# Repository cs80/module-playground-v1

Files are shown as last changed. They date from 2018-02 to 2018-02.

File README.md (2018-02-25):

# module-playground-v1
  Old Crow's Module Playground 10HP Eurorack module using the Adafruit Feather M0/M4 and CircuitPython.
Make sure the feather to be used has at least circuitpython 2.2.x installed as well as the adafruit
circuitpython libraries. See https://github.com/adafruit/circuitpython/releases and
https://learn.adafruit.com/welcome-to-circuitpython/circuitpython-libraries for more info.

  For oc_midicv.py use mpy-cross and place resulting oc_midicv.mpy file in the lib folder of CIRCUITPY:
Rename init_midicv.py to code.py and place in top level of CIRCUITPY: Pre-compiled .mpy is included
here for the lazy hacker. ;)

  The example program oc_midicv.py is too large to run in the M0 memory space which is why it requires
compiling to bytecode (.mpy) to squeeze it down to fit.  mpy-cross is available at the circuitpython
link above.  Note that mpy-cross is a command-line utility.

  The .brd and .sch files are for Eagle CAD for those interested.
  
25-FEB-2018 Scott Rider / The Old Crow

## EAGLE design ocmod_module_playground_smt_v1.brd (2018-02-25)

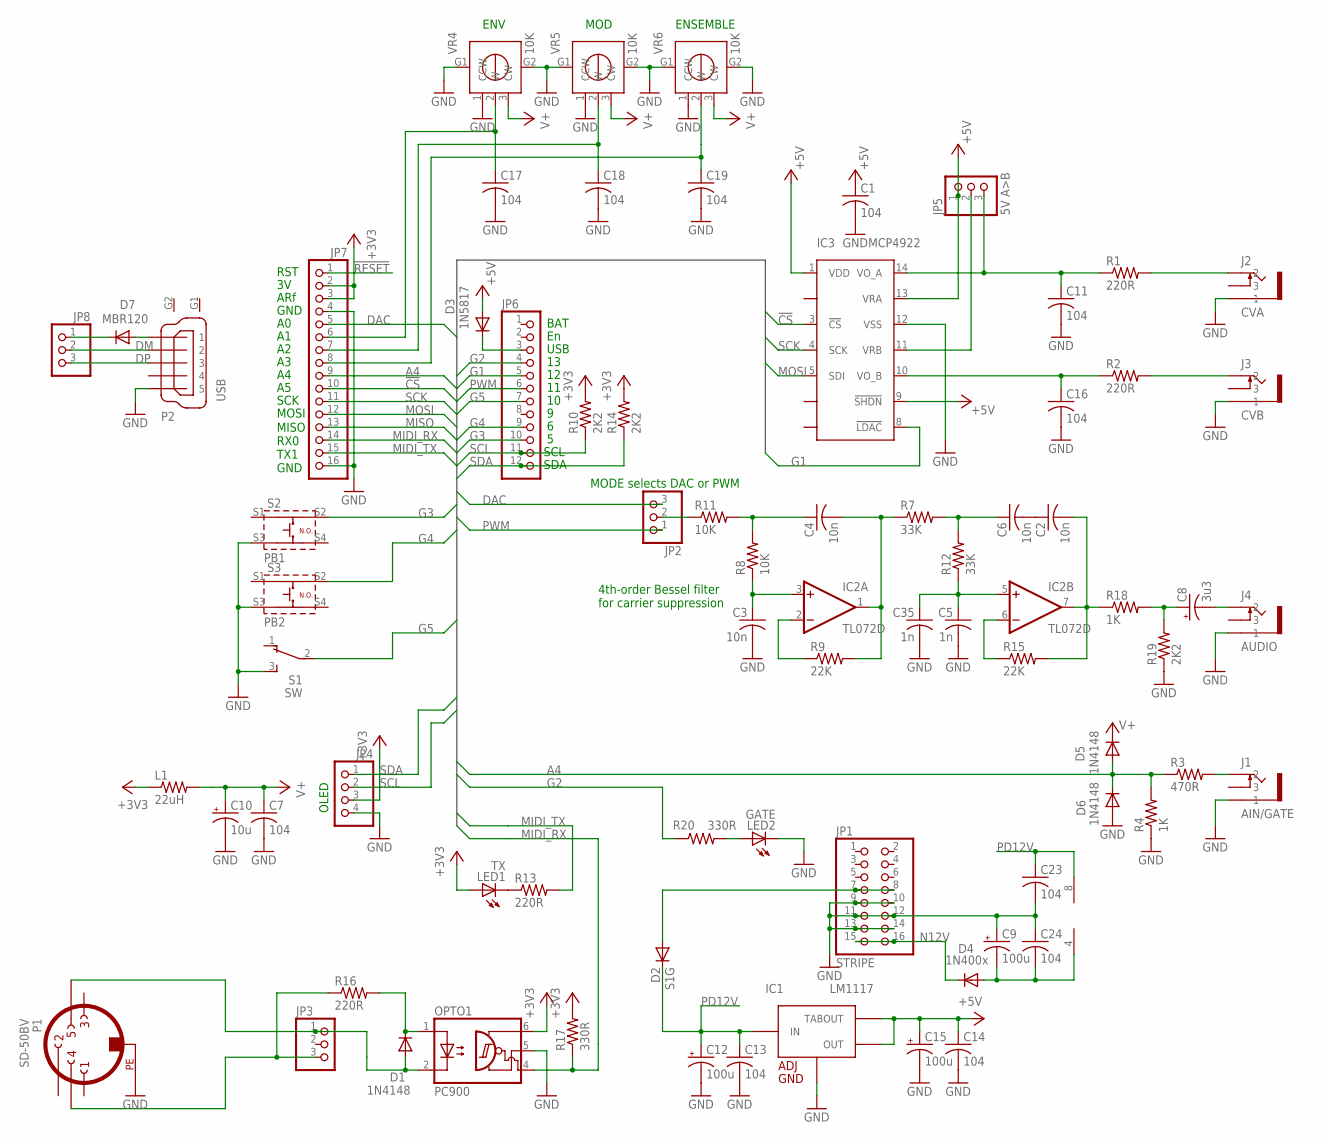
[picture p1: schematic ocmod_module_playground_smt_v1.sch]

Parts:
C1, C7, C11, C13, C14, C16, C17, C18, C19, C23, C24: 104; C0805K
C2, C3, C4, C6: 10n; C0805K
C5, C35: 1n; C0805K
C8: 3u3; B/3528-21R
C9, C12, C15: 100u; B/3528-21R
C10: 10u; B/3528-21R
D1, D5, D6: 1N4148; SOD123
D2: S1G; DO-214AC
D3: 1N5817; DO214AC
D4: 1N400x; DO-214AC
D7: MBR120; SOD123
IC1: LM1117; SOT223
IC2: TL072D; SO08
IC3: MCP4922; SO14
J1: AIN/GATE; WQP-PJ301M-12_JACK
J2: CVA; WQP-PJ301M-12_JACK
J3: CVB; WQP-PJ301M-12_JACK
J4: AUDIO; WQP-PJ301M-12_JACK
JP1: STRIPE; 2X08
JP2, JP3, JP8: PINHD-1X3; 1X03
JP4: PINHD-1X4; 1X04
JP5: 5V A>B; 1X03
JP6: PINHD-1X12; 1X12
JP7: PINHD-1X16; 1X16
L1: 22uH; R0805
LED1: TX; LED3MM
LED2: GATE; LED3MM
OPTO1: PC900; DIL06N
P1: SD-50BV; SD-50BV_P
P2: USB; MINI_USB5_WURTH
R1, R2, R13, R16: 220R; R0805
R3: 470R; R0805
R4, R18: 1K; R0805
R7, R12: 33K; R0805
R8, R11: 10K; R0805
R9, R15: 22K; R0805
R10, R14, R19: 2K2; R0805
R17, R20: 330R; R0805
S1: SW; TL3XPO
S2: PB1; TACTSW_6MM_P
S3: PB2; TACTSW_6MM_P
VR4, VR5, VR6: 10K; ALPHA_9MM_VERT_P

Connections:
!CS!: IC3.3 (!CS), JP7.10
!RESET: JP7.1
+3V3: JP4.3, JP7.2, JP7.3, L1.1, LED1.A, OPTO1.6 (VCC), R10.2, R14.2, R17.2
+5V: C1.1, C14.1, C15.+, D3.A, IC1.1 (TABOUT), IC1.4 (OUT), IC3.1 (VDD), IC3.9 (!SHDN!), IC3.13 (VRA), JP5.1
A4: D5.A, D6.C, JP7.9, R3.1, R4.2
DAC: JP2.3, JP7.5
DM: JP8.2, P2.2
DP: JP8.3, P2.3
G1: IC3.8 (!LDAC), JP6.5
G2: JP6.4, R20.1
G3: JP6.10, S2.S2 (2)
G4: JP6.9, S3.S2 (2)
G5: JP6.7, S1.2
GND: C1.2, C3.2, C5.2, C7.2, C9.+, C10.-, C11.2, C12.-, C13.2, C14.2, C15.-, C16.2, C17.2, C18.2, C19.2, C23.2, C24.1, C35.2, D6.A, IC1.2 (ADJ/GND), IC3.12 (VSS), J1.P$3 (1), J2.P$3 (1), J3.P$3 (1), J4.P$3 (1), JP1.9, JP1.10, JP1.11, JP1.12, JP1.13, JP1.14, JP4.4, JP7.4, JP7.16, LED2.K (C), OPTO1.5 (GND), P1.PE, P2.5, R4.1, R19.1, S1.3 (S), S2.S3 (3), S3.S3 (3), VR4.1 (CCW), VR4.G1, VR4.G2, VR5.1 (CCW), VR5.G1, VR5.G2, VR6.1 (CCW), VR6.G1, VR6.G2
MIDI_RX: JP7.14, OPTO1.4 (VO), R17.1
MIDI_TX: JP7.15, R13.2
MISO: JP7.13
MOSI: IC3.5 (SDI), JP7.12
N12V: D4.C, JP1.15, JP1.16
unnamed: JP2.2, R11.1
unnamed: D3.C, JP6.3
unnamed: C19.1, JP7.8, VR6.2 (W)
unnamed: J3.P$1 (2), R2.2
unnamed: C11.1, IC3.14 (VO_A), JP5.3, R1.1
unnamed: C9.-, C24.2, D4.A, IC2.4 (V-)
unnamed: IC2.2 (-IN), R9.1
unnamed: C4.2, IC2.1 (OUT), R7.1, R9.2
unnamed: C3.1, IC2.3 (+IN), R8.1
unnamed: C4.1, R8.2, R11.2
unnamed: IC2.6 (-IN), R15.1
unnamed: C5.1, C35.1, IC2.5 (+IN), R12.1
unnamed: C6.1, R7.2, R12.2
unnamed: C8.-, J4.P$1 (2)
unnamed: C2.1, C6.2
unnamed: JP3.3, P1.4, R16.1
unnamed: C2.2, IC2.7 (OUT), R15.2, R18.1
unnamed: LED2.A, R20.2
unnamed: C18.1, JP7.7, VR5.2 (W)
unnamed: C17.1, JP7.6, VR4.2 (W)
unnamed: D7.A, P2.1
unnamed: C16.1, IC3.10 (VO_B), R2.1
unnamed: C8.+, R18.2, R19.2
unnamed: LED1.K (C), R13.1
unnamed: J2.P$1 (2), R1.2
unnamed: J1.P$1 (2), R3.2
unnamed: D7.C, JP8.1
unnamed: IC3.11 (VRB), JP5.2
unnamed: D1.A, JP3.1, OPTO1.2 (C), P1.5
unnamed: D1.C, OPTO1.1 (A), R16.2
P12V: D2.A, JP1.7, JP1.8
PD12V: C12.+, C13.1, C23.1, D2.C, IC1.3 (IN), IC2.8 (V+)
PWM: JP2.1, JP6.6
SCK: IC3.4 (SCK), JP7.11
SCL: JP4.2, JP6.11, R10.1
SDA: JP4.1, JP6.12, R14.1
V+: C7.1, C10.+, D5.C, L1.2, VR4.3 (CW), VR5.3 (CW), VR6.3 (CW)

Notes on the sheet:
ENV
ENSEMBLE
MOD
MISO RX0 TX1 GND
RST
ARf
GND
SCK
MOSI
BAT
USB
SCL
SDA
OLED
MODE selects DAC or PWM
4th-order Bessel filter for carrier suppression

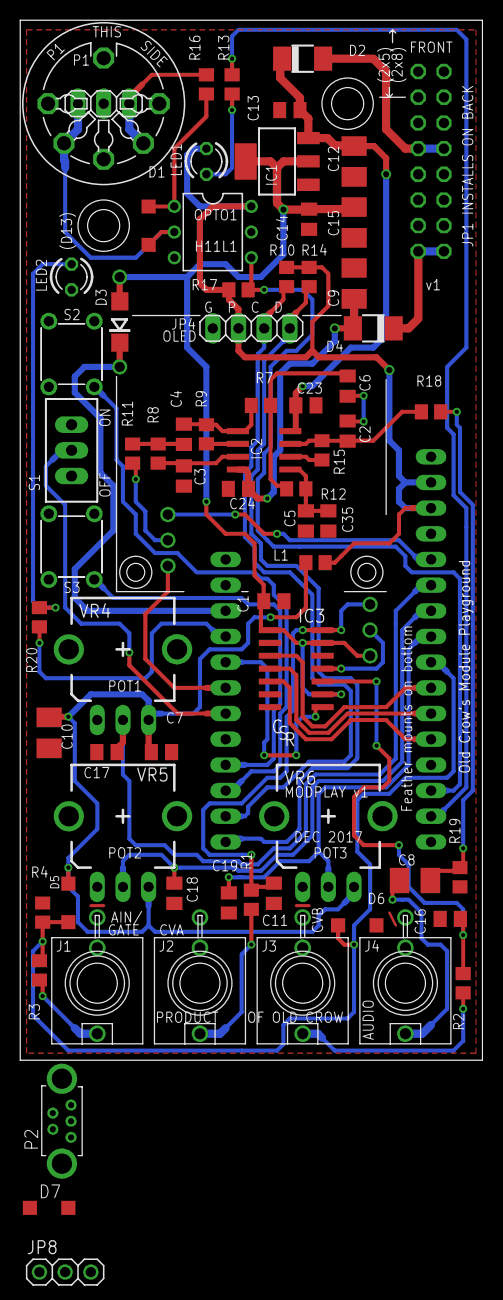
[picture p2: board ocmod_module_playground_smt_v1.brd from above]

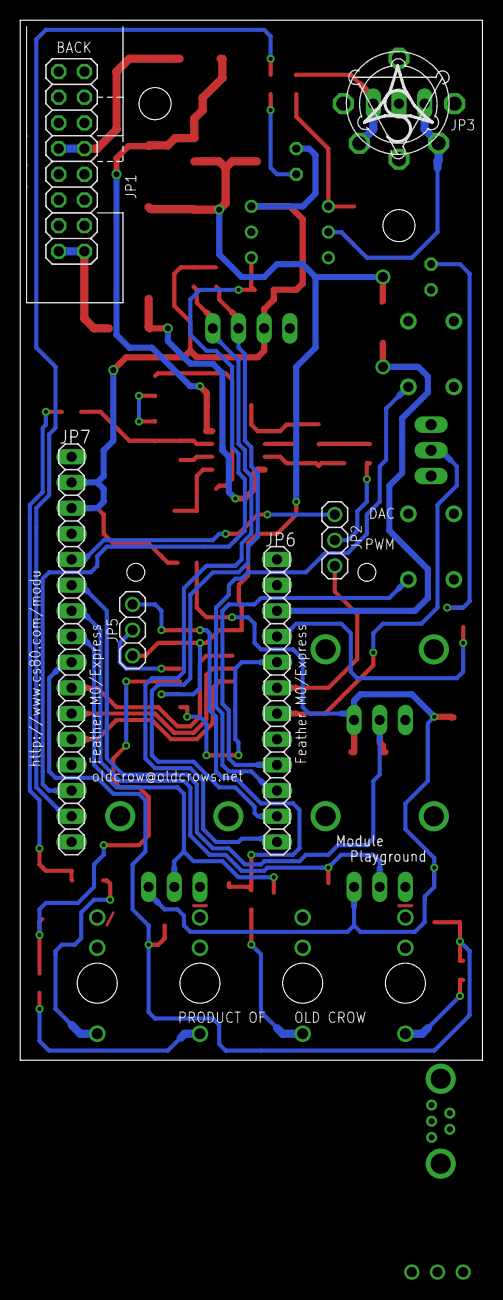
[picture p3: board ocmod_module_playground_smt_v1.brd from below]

Board: 2 copper layers, 45.7 x 102.9 mm, 74 parts (5 on the bottom side), 54 nets.

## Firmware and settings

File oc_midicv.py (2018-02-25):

# Old Crow's MIDICV with CC in CircuitPython
# 20 FEB 2018 21:46

import digitalio
import audioio
import board
import time
import busio
import adafruit_ssd1306
import analogio
from adafruit_waveform import sine

# Create 440Hz sine tone sample and assign to feather's DAC
FREQUENCY = 440    # 440 Hz middle 'A'
SAMPLERATE = 8000  # 8000 samples/second, recommended!
wave = sine.sine_wave(SAMPLERATE, FREQUENCY)
a440 = audioio.AudioOut(board.A0, wave)
a440.frequency = SAMPLERATE

# Initialize MIDI engine states
midiRunningStatus = 0
midiState = 0
midiNoteBufferIndex = 0
midiNoteBuffer = [128, 128, 128, 128, 128, 128, 128, 128, 128, 128]
midiNoteToRemove = 255

# Set up MCP4922 dual DAC
daccs = digitalio.DigitalInOut(board.A5)  # A5 is DAC CS
spi = busio.SPI(board.SCK, board.MOSI)
from adafruit_bus_device.spi_device import SPIDevice
mcp4922 = SPIDevice(spi, daccs, baudrate=8000000, polarity=0, phase=0)

# Initialize knob stuff
cclist = ['Modwheel', 'Breathctrl', 'Aftertouch', 'Velocity']
cvi = [128, 128, 128]
mux = 0

pot = [analogio.AnalogIn(board.A1),
       analogio.AnalogIn(board.A2),
       analogio.AnalogIn(board.A3)]
for i in range(0, 3):
    cvi[i] = pot[i].value
# Normalize current panel settings
midiChan = cvi[0] >> 12 # Channel in range 0~15
midiCC = cvi[1] >> 14 # CC type in range 0~3
cvaAtten = (cvi[2] * 101) // 65536 # CVA attenuate 0~100%

# Set up serial port for MIDI
ser = busio.UART(board.D1, board.D0, baudrate=31250, timeout=1)

# Toggle switch used for 'set/run' to change parameters
switch = digitalio.DigitalInOut(board.D10)
switch.direction = digitalio.Direction.INPUT
switch.pull = digitalio.Pull.UP
swToggledRun = True # Init swa latch

# Pushbutton A used for toggling 440Hz tuning note
pba = digitalio.DigitalInOut(board.D5)
pba.direction = digitalio.Direction.INPUT
pba.pull = digitalio.Pull.UP
pbaState = 1
pbaToggle = 0

# Pushbutton B used for MIDI panic/all notes off
pbb = digitalio.DigitalInOut(board.D6)
pbb.direction = digitalio.Direction.INPUT
pbb.pull = digitalio.Pull.UP
panicPressed = True # Init pbb latch

# D13 used for gate LED, A4 for gate signal
gateLED = digitalio.DigitalInOut(board.D13)
gateLED.direction = digitalio.Direction.OUTPUT
gate = digitalio.DigitalInOut(board.A4)
gate.direction = digitalio.Direction.OUTPUT

# OLED uses i2c at address 0x3C
i2c = busio.I2C(board.SCL, board.SDA)
try:
    oled = adafruit_ssd1306.SSD1306_I2C(128, 64, i2c, addr=0x3c)
    gotOLED = True
except:
    gotOLED = False

if gotOLED: # Splash screen
    oled.fill(0)
    oled.text('Old Crow\'s', 20, 8)
    oled.text('Module', 36, 18)
    oled.text('Playground:', 20, 28)
    oled.text('cktPython MIDICV', 0, 48)
    oled.show()
    time.sleep(2)

# Flush the midiNoteBuffer, used by MIDI controller code 123 (all notes off) as
# well as initialization. Gate is set to inactive.
def clearMidiNoteBuffer():
    global midiNoteBuffer
    global midiNoteToRemove
    global midiNoteBufferIndex
    for i in range(0, 10):
        midiNoteBuffer[i] = 128
    midiNoteBufferIndex = 0
    midiNoteToRemove = 255
    gate.value = 0
    gateLED.value = 0

# Called at the end of processing MIDI note off messages to
# repack the midiNoteBuffer
def compactMidiNoteBuffer():
    global midiNoteBuffer
    global midiNoteToRemove
    global midiNoteBufferIndex
    for i in range(1, 9):
        if midiNoteBuffer[i] == midiNoteToRemove:  # Maintain midiNoteBuffer
            midiNoteBuffer[i] = 128    # Clear note entry
            midiNoteToRemove = 255     # Unflag the now-removed note
            midiNoteBufferIndex -= 1   # Shrink filled buffer count

        if midiNoteBuffer[i] == 128:   # If current buffer location empty
            midiNoteBuffer[i] = midiNoteBuffer[i + 1]  # compact buffer
            midiNoteBuffer[i + 1] = 128  # justify with "slot empty" value

# Output on DAC channel 1 (half-scale)
def outputCV1(val, att):
    # 0x3xxx is DAC channel 1, gain=1x, no vref buffer, output active
    val = (val * att) // 100
    dacData = bytearray(2)
    dacData[0] = ((val >> 3) & 0x0F) | 0x30
    dacData[1] = (val << 5) & 0xF0
    with mcp4922:
        spi.write(dacData)

# Output on DAC channel 2
def outputCV2(note):
    while note > 84:
        note -= 12  # Wrap notes above C6 to highest usable octave
    while note < 24:
        note += 12  # Wrap notes below C1 to lowest usable octave
    x = (note - 24) * 273  # Magic formula for semitone scale (n-t)*4095/60
    y = (x >> 2) + ((x >> 1) & 1)  # Round for 0.5 LSB accuracy
    # 0xBxxx is DAC channel 2, gain=1x, no vref buffer, output active
    dacData = bytearray(2)
    dacData[0] = ((y >> 8) & 0x0F) | 0xB0
    dacData[1] = y & 0xFF
    with mcp4922:
        spi.write(dacData)

def handleNoteOn(note, val):
    global midiNoteBufferIndex
    global midiNoteBuffer
    global midiNoteToRemove
    global midiNoteLegato
    if val != 0:
        midiNoteBufferIndex += 1
        midiNoteBuffer[midiNoteBufferIndex] = note  # Add newest note to buffer
        outputCV2(note)  # Send to DAC
        gate.value = 1  # Gate high
        gateLED.value = 1
        if midiCC == 3: # Use key velocity if selected for CVA
            outputCV1(val, cvaAtten)
        if midiNoteBufferIndex == 9:  # Buffer full? Limit to 8 notes
            midiNoteBuffer[1] == 128  # Flag oldest entry for removal
            midiNoteBufferIndex -= 1  # Back out to 8th entry
    else:  # Velocity zero note off
        handleNoteOff(note)

def handleNoteOff(note):
    global midiNoteBufferIndex
    global midiNoteBuffer
    global midiNoteToRemove
    global midiNoteLegato
    midiNoteToRemove = note  # Flag note to clear from buffer
    # If current note is to be turned off
    if midiNoteBuffer[midiNoteBufferIndex] == midiNoteToRemove:
        # Then provided buffer is not empty
        if midiNoteBufferIndex > 0:
            # and it is not the only note playing
            if (midiNoteBufferIndex - 1) > 0:
                # play the previous note
                midiNoteLegato = midiNoteBuffer[midiNoteBufferIndex - 1]
                outputCV2(midiNoteLegato)  # legato-style (no retrigger)
    compactMidiNoteBuffer()  # Manage note buffer

def handleMidiCC(cc, val):
    if cc == 123 and val == 0:
        clearMidiNoteBuffer()
        return
    if cc == midiCC + 1:
        outputCV1(val, cvaAtten)
        return

def doMIDI(mrx: bytes):
    global midiRunningStatus
    global midiState
    global midiNote
    global midiVel
    global midiChan
    if mrx > 0xEF and mrx < 0xF8:  # ignore mode messages
        midiRunningStatus = 0
        midiState = 0
        return

    if mrx > 0xF7:
        return  # bail on realtime leaving previous status

    if mrx & 0x80:  # got a command byte
        midiRunningStatus = mrx
        midiRcvChan = midiRunningStatus & 0x0F
        if midiRcvChan == midiChan:  # Check channel number
            midiState = 1
        else:
            midiRunningStatus = 0
            midiState = 0
        return

    if mrx < 0x80:  # if data byte assign it
        if not midiRunningStatus:
            return

        if midiState == 1:
            midiNote = mrx  # got a note value
            if midiRunningStatus > 0xBF and midiRunningStatus < 0xE0:
                midiState = 1 #  For 2-byte messages
                midiVel = 0
            else:
                midiState = 2 #  For 3-byte messages
                return

        if midiState == 2:
            midiVel = mrx  # got a velocity value
            midiState = 1

        if midiRunningStatus == 0x90: # Note on
            handleNoteOn(midiNote, midiVel)
            return

        if midiRunningStatus == 0x80: # Note off
            handleNoteOff(midiNote)
            return

        if (midiRunningStatus == 0xB0) and (midiCC < 2): # CC
            handleMidiCC(midiNote, midiVel) #  controller, data
            return

        if (midiRunningStatus == 0xD0) and (midiCC == 2): # AT
            handleMidiCC(3, midiNote) #  1st data is AT
            
def updateOLED(mode, cc, atten):
    oled.fill(0)
    mode = 'MIDICV: ' + mode
    cctype = 'CVA: ' + cclist[cc]
    atten = 'CVA level: ' + str(atten) + '%'
    oled.text('<CircuitPython!>', 0, 0, 1)
    oled.text(mode, 0, 20, 1)
    oled.text('MIDI channel: %d' % midiChan, 0, 30, 1)
    oled.text(cctype, 0, 40, 1)
    oled.text(atten, 0, 50, 1)
    oled.show()

while True:
    # Read the 3 pots one at a time
    # Exponentially-weighted sample averaging
    cvi[mux] += (pot[mux].value - cvi[mux]) >> 2
    mux += 1
    if mux > 2:
        mux = 0

    if switch.value: # "set" mode
        midiChan = cvi[0] >> 12 # Channel in range 0~15
        midiCC = cvi[1] >> 14 # CC type in range 0~3
        cvaAtten = (cvi[2] * 101) // 65536 #  1% steps for CVA fullscale
        swToggledRun = True
        if gotOLED:
            if pbaToggle:
                updateOLED('A440', midiCC, cvaAtten)
            else:
                updateOLED('SET', midiCC, cvaAtten)
        # Panic button (PBB) to clear stuck notes
        if not pbb.value and panicPressed:
            handleMidiCC(123, 0) # Controller code 123 is all notes off
            panicPressed = False
        elif pbb.value and not panicPressed:
            panicPressed = True
        
    else:            # "run" mode
        if swToggledRun:
            if gotOLED:
                if pbaToggle:
                    updateOLED('A440', midiCC, cvaAtten)
                else:
                    updateOLED('RUN', midiCC, cvaAtten)
            swToggledRun = False

        midiRX = ser.read(1)
        if midiRX:
            rcv = midiRX[0]
            doMIDI(rcv)

    # Manage PBA push-to-toggle for A440
    pbaRead = pba.value
    if pbaRead != pbaState:
        pbaState = pbaRead
        if not pbaState:
            pbaToggle = not pbaToggle
            if pbaToggle:
                if gotOLED:
                    updateOLED('A440', midiCC, cvaAtten)
                a440.play(loop=True)
            else:
                if gotOLED:
                    if switch.value:
                        updateOLED('SET', midiCC, cvaAtten)
                    else:
                        updateOLED('RUN', midiCC, cvaAtten)
                a440.stop()
	
    # Release gate signal if no notes left
    if midiNoteBufferIndex == 0:
        gate.value = 0
        gateLED.value = 0

# Code end
